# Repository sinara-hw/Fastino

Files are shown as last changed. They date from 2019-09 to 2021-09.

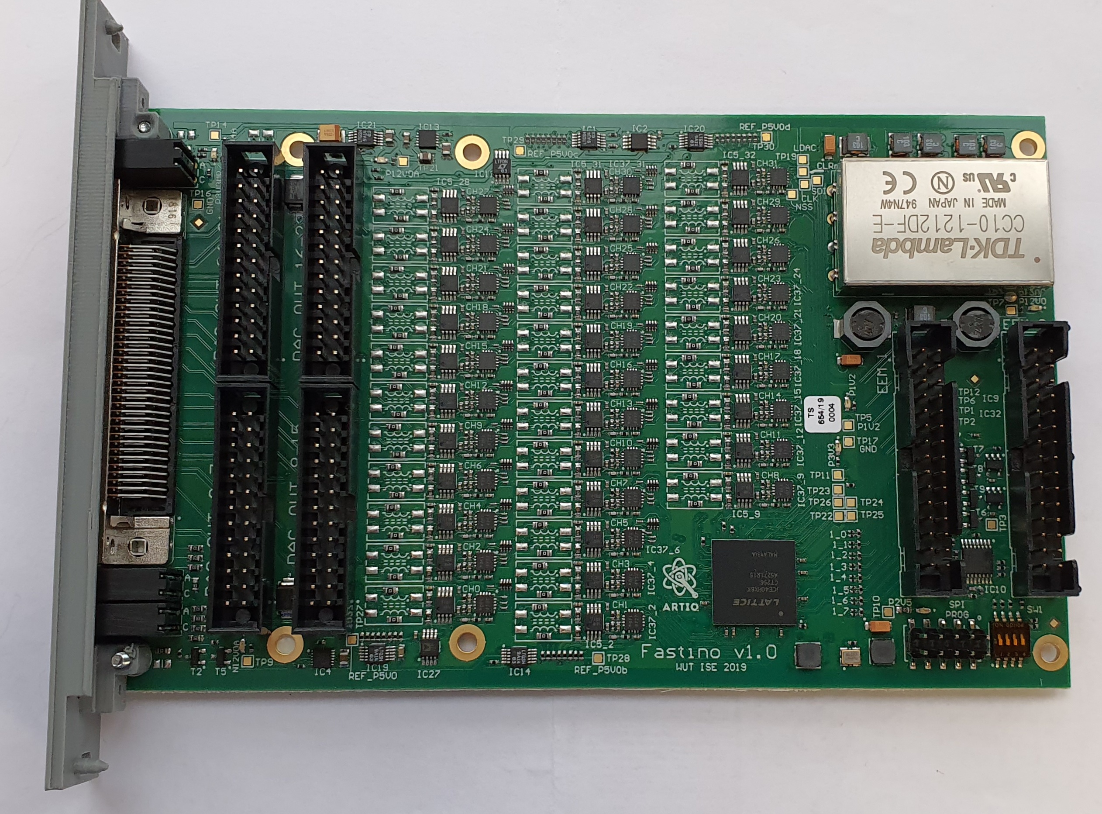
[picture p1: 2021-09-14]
2019-12-04 11.57.32.jpg

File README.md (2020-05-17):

# Fastino
Fast 32-channel, 3MS/s per channel, 16bit DAC EEM card compatible with Zotino

## Design Files

Design files (schematics, PCB layouts, BOMs) can be found at [Fastino/Releases](https://github.com/sinara-hw/Fastino/releases).

## Wiki

More information can be found on the [wiki](https://github.com/sinara-hw/Fastino/wiki).

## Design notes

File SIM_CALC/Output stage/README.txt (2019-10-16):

LTspice output stage simulations
================================

This directory contains the LTspice source files used in the 
design phase of the Fastino output stage.

 - Design.asc: The proposed output stage design.
 - Design Monte-Carlo tolerance analysis.asc: A component
   tolerance analysis for the proposed design (mc() in LTspice
   uniformly samples from the given relative tolerance region).
 - Design with MFB second stage.asc: An alternative design
   providing enhanced high-frequency roll-off at the cost of an
   extra matched resistor pair and slightly increased noise and
   power dissipation.
 - Noise estimate using DAC matched Rs.asc: A quick estimate of
   the output noise from the DAC-internal matched resistor pair.
 - Stabilizer output stage design.asc: For comparison, the
   output stage of the Stabilizer v1.0 two-channel
   microcontroller servo.

The macromodels for the OPA197 and AD8620 can be downloaded from
the respective manufacturer's websites; place them somewhere on
the library search path (in the easiest case, this directory):

 - http://www.ti.com/product/OPA197/toolssoftware
   (the PSpice model can be used with LTSpice)
 - https://www.analog.com/media/en/simulation-models/spice-models/ad8620.cir

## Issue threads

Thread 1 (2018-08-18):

[RFC] new EEM: Fastino (faster version of Zotino)

dtcallcock, 2018-08-18:
A faster DAC than Zotino.

Roughly order of magnitude performance improvement by most metrics at the cost ob being only 4 channels.

# Use cases

### Voltage output version of SU servo

[SU servo](https://github.com/m-labs/artiq/tree/master/artiq/gateware/suservo) is an 8ch servo for Artiq based on [Kasli](https://github.com/sinara-hw/Kasli).  It uses the 8ch [Sampler](https://github.com/sinara-hw/Sampler) ADC as the input and changes the phase/amplitude/frequency of a pair of [Urukul](https://github.com/sinara-hw/Urukul) 4ch DDS cards as its output.  It is capable of a ~2us latency.  An obvious extension of SU servo would be to have a voltage output instead.  This would reuse the Sampler, Kasli, and much of the gateware.  The current EEM DAC, [Zotino](https://github.com/sinara-hw/Zotino) is not well suited for this application for various reasons though.

### General fast DAC

There is a bit of a gap between Zotino (update rate of 1MSPS divided between all 32 channels) and the super high spec [Shuttler](https://github.com/sinara-hw/sinara/wiki/Shuttler).  Are there any specific use cases to be found in this gap?

# Implementation

### Channel Count

4 channels and 4 SMAs on a 4HP front panel

### DACs

4x 16-bit single channel DACs
[AD5542a](http://www.analog.com/en/products/ad5542a.html) or similar

3 MSPS (all channels simultaneously)
1 LSB INL (4x)
11.8 nV/√Hz noise spectral density (23x)
1 μs settling time (20x)
0.05 ppm/°C temperature drift (100x)

Numbers in brackets refer to improvement over the [AD5372](http://www.analog.com/media/en/technical-documentation/data-sheets/AD5372_5373.pdf) on Zotino.

### EEM

1x SCLK
4x SDI
1x LDAC
1x CLR
1x spare

I2C readout of termination and polarity settings.

### Output Ranges

Output impedance of 450Ohm

Bipolar
- -1 to 1V into 50 Ohm load
- -10 to +10V into high-Z load

Unipolar
- 0 to 1V into 50 Ohm load
- 0 to 10V into high-Z load

DIP switch to select between bipolar/unipolar.
DIP switch to connect on-board 50 termination.

gkasprow, 2019-01-13:
Anyway, let's wait until we debug the Stabilizer (DAC part) and Banker (FPGA part) first.

hartytp, 2019-07-07:
Thoughts about Fastino having played around with Stabilizer:
- Generally, looks like we can reuse the analog parts from Stabilizer without major changes
- The in-band noise is basically white at ~100nV/rtHz. That agrees with a back of the envelope from the schematic; DAC is 12nV/rtHz (and there aren't really any lower noise options); AFE gain is 5 to get +-10V with 4.096Vref (can potentially use a gain of 4 with 5V ref but there is the usual issue around ensuring that the supply voltage is actually higher than the reference voltage once accuracy of all components is accounted for); the rest is largely due to the Johnson noise of the ~10k resistors we're using in the AFE. For reference, the NIST PDQ is also around 100nV/rtHz and the ETH "DEATH" boards are around 70nV/rtHz. We could get the noise down a bit by e.g. increasing the ref voltage (decrease AFE gain) and decreasing the resistors used in the dividers. Before doing that we should consider what we actually need for experiments and whether it's worth the fuss
- Still need to measure the noise at higher frequencies to check what the active filter is doing. My guess is that it doesn't do much since the final stage noise + gain is still relatively high (again due to the 10k resistors). Probably fine as we can put a passive filter near the trap, but worth having a think about this.
- The reference buffer solution on Stabilizer seems good. We may be able to get away with 1 ref buffer per 8 (or more) DACs (instead of the 4:1 ratio on Stabilizer) particularly if we switch to the LT3045 (lower output impedance), but needs simulation.
- The major piece of work is the digital section (deserializer interface) which needs to be prototyped before we can actually start on the HW

gkasprow, 2019-07-07:
The deserializer can be easily prototyped with Humpback. I plan to reuse its digital section entirely. The sampler can be attached to it and SPI lines can be directly routed to the FPGA after removing the '125 buffers.

hartytp, 2019-07-07:
> The deserializer can be easily prototyped with Humpback. I plan to reuse its digital section entirely.

I'm not so worried about prototyping on HW itself -- you've shown that you can lay out FPGA/CPLD projects like this very reliably. What I'm thinking about is writing the code ahead of time and checking it builds, meets timing, etc. It's not a huge job, but it needs some thought to get right

gkasprow, 2019-07-07:
the question is if we want to have independent control of all DACs? Or we can assume that they will be updated simultaneously and we can route common CLK  and NSS lines. We have ~90 3.3V IO lines. Rest are in the 2.5V bank. We can route only 2 dedicated lines per DAC. If we add 2.5-> 3.3V converter we could route 3 individual lines to every DAC, but I'm not sure if that is necessary.

hartytp, 2019-07-07:
Yes, it needs some thought. I have some ideas, but I'd prefer not to start a conversation about it until I've given it some more thought :)

gkasprow, 2019-07-07:
Another question we need to ask is the application. Is the board going to be used for fast update of a single channel, massive streaming of data to all channels or both? And, is the latency critical?

jordens, 2019-08-29:
@gkasprow could you give me write access? I'd like to add specification and details to the wiki.

jordens, 2019-08-29:
@gkasprow Are you sure about that IO count? On Banker you have routed 128 IOs plus 16 direction signals on three banks that could be 3.3V (not counting the LVDS bank at 2.5V). That would map to 4 signals per DAC plus spares for LEDs and shared CLR.

gkasprow, 2019-08-29:
@jordens I assumed that will have only two EEM connectors. Some of 2.5V can be used for 3.3V signaling as outputs.

gkasprow, 2019-08-29:
I gave you access rights.

jordens, 2019-08-29:
Even with three eem connectors there should be enough io to give each dac 4  lvcmos 3.3 signals. That's sufficient for completely independent control. Clr can be shared.

gkasprow, 2019-08-29:
True. I didn't count one bank. We have enough pins.

gkasprow, 2019-08-30:
Is there any use case for 3 EEMs?

hartytp, 2019-08-30:
> Is there any use case for 3 EEMs?

I don't think so. My assumption is that we can probably run the whole thing from a single EEM (see Robert's spec on the Wiki), but having a second one for contingency/expansion is a good idea. That would still allow us (ignoring current consumption, heat etc) to drive 192 DAC channels per Kasli.

hartytp, 2019-09-06:
Hardware, gateware and software funded by U Oxford

Closed 2019-09-06.

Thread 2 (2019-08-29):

analog design notes

hartytp, 2019-08-29:
**noise density**
- for HOA2, 43Ca+, 1MHz secular frequency: 0.5nV/rtHz on all electrodes (uncorrelated) gives 10qps (quanta per second) heating rate
- heating rate is quadratic in voltage noise density (linear in PSD)
- heating rate scales as inverse of secular frequency
- we'd like to aim for <1nv/rtHz at our trap, assuming a passive multi-pole RC filter between Fastino and the trap
- assume we use a filter like https://ws680.nist.gov/publication/get_pdf.cfm?pub_id=912958 and assume Fastino has an output resistance of around 33 Ohm (to isolate the OpAmp from cable capacitance)
- assume we get around 35dB of filtering, that's a factor of ~50 in linear units. So, the noise density out of Fastino in the stop-band of the Fastino's filters needs to be <~50nV/rtHz, which isn't trivial but should be doable with careful design.

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

- rough ball-park of heating during a splitting operation. Suppose the secular frequency drops down to 300kHz for 30us and we want to limit axial heating to <1 phonon. That's a max heating rate of 33kHz at the lower frequency
- for 1MHz secular, that would be a noise density of `0.5*sqrt(33e3/10)=30nV/rtHz`. For 300kHz it needs to be 10 quanta/second.
- We'll likely be in the 50-100nV/rtHz, so heat by 25-100quanta over that splitting operation.
- noise sources:
  - AD5542A (DAC) Vn =12nV/rtHz after an AFE gain of 5 that's 60nV/rtHz. IIRC there isn't a significantly lower noise DAC around at this kind of BW, so this is a fairly hard limit. Only affects "in-band" noise though as removed by AFE filter stages
  - AD8620ARZ (AFE OpAmp) Vn=6nV/rtHz. IIRC the noise from the second OpAmp is still present after the filter with a gain of 2.5, so that's 15nV/rtHz which is fine.
  - OpAmp In negligible since JFET
  - [ ] to do: SPICE noise model for Stabilizer, look at relative contributions. Measure on current hardware to check reality matches the model

@dnadlinger IIRC you had a nice table of the noise for the various "fast DAC" cards around. Would you mind posting that for reference?

**slew rate**
- I'd like to be able to output FS sinusoids at a few hundred kHz without being slew-rate limited
- peak slew-rate limited is `10V*2*pi*300kHz=12.6V/us` (in practice a little less is needed due to attenuation by the filter)
- the DAC has a slew rate of 17V/us after an AFE gain of 5 that's 85V/us
- the AD8620ARZ used on Stabilizer has a slew rate of min 40V/us
- so this should be completely fine!

**other comments**
- since we're using much more stable DACs than Zotino (and stable dividers) we don't need a TEC
- we'll need to do proper PI and thermal simulations to check how hot this gets

hartytp, 2019-08-29:
From Ludwig's thesis:

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

So the in-band noise would be about the same as the ETH cards.

dnadlinger, 2019-08-29:
Yep, the table I had was the one from Ludwig's thesis you posted.

hartytp, 2019-08-29:
- [ ] to check: can we switch to a 5V ref and 4xAFE gain for slightly lower noise?

hartytp, 2019-08-29:
> to check: can we switch to a 5V ref and 4xAFE gain for slightly lower noise?

AFAICT the DAC is fine with Vref=Vsupply=5.5V. IIRC the choice of 4.096V for Stabilizer was because of the ADCs, not the DACs.

For 5.5Vref we'd get nearly a factor of 2 reduction in heating rate for low axial frequencies which is definitely worth having. Lowering the gain of the final stage also lowers the out-of-band noise floor so all around a good thing to do. But, needs double checking from the data sheet that this is allowed.

dnadlinger, 2019-08-30:
Regarding op-amp noise, the OPA827 is 4 nV/rtHz at 1 kHz, i.e. 33% lower. Slew rate needs a look, though.

hartytp, 2019-08-30:
> Regarding op-amp noise, the OPA827 is 4 nV/rtHz at 1 kHz, i.e. 33% lower than the AD8620, and cheaper as well. Slew rate needs a look, though.

IIRC I rejected that originally because I wanted a dual OpAmp.

Not sure if we have the board real-estate for singles. Since the DAC is 11nV/rtHz the OpAmp noise does alter the overall output noise that much, although lower cost is good...

hartytp, 2019-08-30:
> and cheaper as well.

Not really since you'd need two of them and only one OPA8620

jordens, 2019-08-30:
The other relevant quantity here is the the output range. The +-10V is sounds about right for larger traps (i.e. HOA2 with 140µm characteristic distance). But smaller traps can live happily with less range. And even going to -4 to +8V would help with the noise. IME transport waveforms tend to be pretty asymmetric and need more positive headroom. At least in the traps that I built and worked with. Dunno for HOA2.

dnadlinger, 2019-08-30:
Ah, right, I only had a look at singles. I actually meant the new OPA828, though, but that is still only single, and not available in packages smaller than SOIC.  £3.51 in qty 1000 on Digi-Key, though, vs. £9.95 for the AD8620ARZ.

jordens, 2019-08-30:
And do check the quiescent current. The fancier opamps sometimes buy low noise with lots of quiescent bias current for internal stages.

gkasprow, 2019-08-30:
If we get rid of CMCs, we would spare some real estate for the second opamp.

hartytp, 2019-08-30:
> If we get rid of CMCs, we would spare some real estate for the second opamp.

Sure. All things equal, I'd still prefer to use dual OpAmps though and keep the layout compact.

> And do check the quiescent current. The fancier opamps sometimes buy low noise with lots of quiescent bias current for internal stages.

Yes, thermal/power issues are high on my list of concerns for this design.

dtcallcock, 2019-08-31:
> The +-10V is sounds about right for larger traps (i.e. HOA2 with 140µm characteristic distance).

HOA 2 is rated to +/-20V according to the [manual](https://prod.sandia.gov/techlib/access-control.cgi/2016/160796r.pdf).  Might be worth checking if users of overly-bulky ions like Yb+ actually make use of this capability? @jbqubit ?

> And even going to -4 to +8V would help with the noise. IME transport waveforms tend to be pretty asymmetric and need more positive headroom.

OPA8620 is a 26V opamp so if we went this route perhaps we could make it so that one could switch between -4/+8 and -8/+16 (probably via population options)?

hartytp, 2019-08-31:
@jordens
> The other relevant quantity here is the the output range. The +-10V is sounds about right for larger traps (i.e. HOA2 with 140µm characteristic distance). But smaller traps can live happily with less range. And even going to -4 to +8V would help with the noise. IME transport waveforms tend to be pretty asymmetric and need more positive headroom. At least in the traps that I built and worked with. Dunno for HOA2.

@dtcallcock
> HOA 2 is rated to +/-20V according to the manual. Might be worth checking if users of overly-bulky ions like Yb+ actually make use of this capability? @jbqubit ?
> OPA8620 is a 26V opamp so if we went this route perhaps we could make it so that one could switch between -4/+8 and -8/+16 (probably via population options)?

These are all valid points. Taking a step back for a moment, I think it's important to have a clear mission statement for any project to avoid a bloated, overly-complicated design.
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
hartytp, 2019-09-02:
I'm not too worried about the larger offsets, since the [divider resistors](http://www.farnell.com/datasheets/1932989.pdf?_ga=2.39542499.197723750.1567441610-1538663289.1567441610) are only good to 5e-4 ratio = 10mV on 20V.

So, I'd say the next step is to simulate the filter transfer function for a few different OpAmps from that selection and pick the lowest current consumption amp that does the job. Agreed?

dnadlinger, 2019-09-02:
> Agreed?

Yep; basically, if the OPA2197 is quick enough, there is little reason to look somewhere else. ADA4625 or OPA828 for faster JFET amps with significantly lower 1/f noise.

hartytp, 2019-09-02:
> ADA4625 and OPA828

I discarded those because they're quite pricey and thirsty so I don't really see the appeal over the significantly cheaper OPA2156.

> with significantly lower 1/f noise.

Is that a concern? LTC6655 is 0.25ppm 1/f noise, so 5uV on 20V output. All the amps you selected have low 1/f noise compared with that, so it's not worth worrying about, right?

dnadlinger, 2019-09-02:
> low 1/f noise […] not worth worrying about, right?

1.9 µV over 5.5 V is 0.4 ppm, plus if we really wanted, we could filter down the LTC6655 further using a quiet chopamp and capacitor-leakage-reduced RC filter setup. I don't think this is necessarily worth worrying about, though.

hartytp, 2019-09-02:
> 1.9 µV over 5.5 V is 0.4 ppm

Thank you, yes you're right, it is more important for the first OpAmp. Still, even then we're close to reference limited. I'd argue that I'd prefer reduced cost/current consumption to a factor of 2 in 1/f noise for this design.

Or, a different argument: it's actually quite hard to hit the reference's 0.25ppm noise floor, particularly in an environment with high thermal loads. I suspect that unless we keep the power dissipation down and maybe pot it, we'll measure a few times that. In which case, the OpAmps will contribute but probably not dominate.

dnadlinger, 2019-09-02:
> it's actually quite hard to hit the reference's 0.25ppm noise floor

Agreed; Fastino just flapping around in the (rack fan) will almost certainly be worse than 0.4 ppm; even more so the full system. I just wanted to point out that the design isn't optimised for low-frequency noise, in case someone thinks they'll be limited by it in their use case. May they speak now, or…

hartytp, 2019-09-03:
Tina TI simulation of the filter on stabilizer

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

With the OPAx156 TF is
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

OPA197:
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

hartytp, 2019-09-03:
So, I'd actually argue that the filter performance isn't enough justification to go for the faster OpAmps.

Anyone against going for an OPA2197 for the active filter (and also on stabilizer)?

hartytp, 2019-09-03:
I'm **much** more worried about power dissipation than a few dB on the active filter.

hartytp, 2019-09-03:
Slew rate is 20V/us, which is fine

dnadlinger, 2019-09-03:
We can also go to a multiple-feedback topology for better high-frequency attenuation, although I suppose we'd be more sensitive to part-to-part variations.

hartytp, 2019-09-03:
> We can also go to a multiple-feedback topology for better high-frequency attenuation, although I suppose we'd be more sensitive to part-to-part variations.

True. Feel free to suggest something ;)

jbqubit, 2019-09-03:
> Yeah, and looking at the strike-throughs on the Sinara team page,
> I'm not sure there are even any Yb-ers left.

There's quite a few Yb+ Sinara users. Currently using Sinara there are 5 traps at UMD and 3 traps at DOD  labs. Soon there will be 3 more Yb+ traps at UMD using Sinara. I'll pester people locally who are following the Sinara hardware discussions to add themselves to the sinara [wiki](https://github.com/sinara-hw/meta/wiki/Team#umd).

>HOA 2 is rated to +/-20V according to the manual.
>Might be worth checking if users of overly-bulky ions
>like Yb+ actually make use of this capability? @jbqubit ?

Assuming 171Yb+, HOA-2.0, +/-1 V and potential optimization to maximum axial frequency the result is 700 kHz. +/-10 V would give 2.2 MHz, pretty much the bare minimum. I'd say +/- 20 V is desirable but not at the cost of missing other design objectives.

> On the subject of asymmetric voltage ranges:

Agreed that this is an unwanted level of optimization. Let's keep this somewhat general purpose.

hartytp, 2019-09-03:
Let’s aim to do our best to support higher voltage ranges as a population option (above +-16V or so will need a different opamp). This will need different voltage set resistors for the regulators, different gain set and filter rcs is etc so it’s not something we’ll do now but interested parties can do it when the need arises

Closed 2019-09-07.

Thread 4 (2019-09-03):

filter design

hartytp, 2019-09-03:
Noise plot for the stabilizer filter with OPAx197:
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

- [ ] reduce gain to 2x since we'll use a 5Vref and re-simulate
- [ ] look into reducing the peaking

This looks rather noisy all-told. Worth at least considering reducing resistor values.

@gkasprow how did you calculate the filer components?

hartytp, 2019-09-03:
Scale all impedances down an OOM to reduce the noise and look again at the FT

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

The noise does decrease, but so does the filter response, suggesting that the non-idealities for the OpAmp are a real limitation here. Probably less of an issue with a lower gain, but strongly suggests we need to do some work on filter design

gkasprow, 2019-09-03:
That's why I added 7.5pF cap to compensate for opamp Cin. You should not change it.

hartytp, 2019-09-03:
> That's why I added 7.5pF cap to compensate for opamp Cin. You should not change it.

Okay, but for this filter/OpAmp 7p5 isn't enough. Anyway, requires some tuning. Where did you get the other component values from though?

gkasprow, 2019-09-03:
I selected value to create a compensated divider. It may need tweaking.

gkasprow, 2019-09-03:
The other values were proposed by ADI filter wizard.

hartytp, 2019-09-03:
> The other values were proposed by ADI filter wizard.

Thanks!

hartytp, 2019-09-03:
@gkasprow what filter did you design? Butterworth? What cut-off and Q?

Note to self one of many references on filter design http://www.ti.com/lit/an/sloa049b/sloa049b.pdf (p7 for MFB)

gkasprow, 2019-09-03:
I don't remember. It should be in the design files I gave you access to.

hartytp, 2019-09-03:
@dnadlinger MFB is indeed significantly better in terms of attenuation. Needs a bit of tuning to trade off noise peaking v attenuation and also a Monte-Carlo sim to look at gain tolerance.

dnadlinger, 2019-09-03:
@gkasprow: Do you have any experience with MFB (vs. Sallen-Key) low-pass filters in precision circuits? I'm basically waiting someone to tell me that MFB is a silly idea for a reason I didn't consider.

hartytp, 2019-09-03:
@dnadlinger the biggest reason I'm aware of is that the AC gain becomes sensitive to component values in a way it's not for SK.

hartytp, 2019-09-03:
First thing to fix is the resistor network values. 1k would be great for noise, but then you're looking at the OpAmp sourcing/sinking up to 10mA. Which seems to much if we want any appreciable channel density. So, I guess we need to set the minimum resitance that we source/sink the full 10V through to be something like 10k, which is a bit painful from a noise perspective, but not much choice.

gkasprow, 2019-09-03:
I never tried MFB

hartytp, 2019-09-03:
I think if you do the spice sim and monte-carol to check the tolerances then you'll get all the info you need. Maybe also just check the step response for good measure.

dnadlinger, 2019-09-03:
Re MFB, I'm more worried about non-obvious gotchas (op-amp GBW changes, etc.), which I can't easily Monte-Carlo-simulate in LTSpice. From what I've seen, many people seem to prefer Sallen-Key, but I'm unsure as to why.

Slight changes in step response with component tolerances wouldn't be too big of an issue – if you really care (for accurate transport/pre-emphasis), you'd measure the transfer function of all your filters up to the trap per-channel anyway. Weird drifts, on the other hand, would screw us (although I don't have a good sensitivity estimate for that).

I guess the issue with power dissipation re channel density would mostly be potential drifts induced by the DAC code-dependent heat load? 100 mW * 32 = 3.2 W doesn't seem to be an insurmountable problem.

hartytp, 2019-09-03:
> I guess the issue with power dissipation re channel density would mostly be potential drifts induced by the DAC code-dependent heat load? 100 mW * 32 = 3.2 W doesn't seem to be an insurmountable problem.

Not insurmountable, but still quite a lot of power! (And actually worse than your calculation since one OpAmp sources while the other sinks, 12V rails not 10V etc). Add to the quiescent current and the the board is drawing quite a lot of current.

As you say, my worries are mainly thermal heat load, and particular dynamic thermal heat load making things unstable.

10k shouldn't be too bad since the in-band noise is still dominated by the DAC, while the high-frequency stuff (a) can be removed by a later passive filter (b) for the MFB topology, I think it's capacitively shunted away in any case, so not a problem.

hartytp, 2019-09-03:
@dnadlinger http://www.ti.com/lit/an/sbfa001c/sbfa001c.pdf p10-11

dnadlinger, 2019-09-03:
@hartytp: Thanks – yep, those were the points I was aware of (without gain, the op-amp in Sallen–Key is just a follower, so no stable DC gain setting resistor pair needed), but people just seems to use it by default even in situations where the lack of high-frequency attenuation hurts… I'll (LT)Spice up a design in a bit once I got that two-qubit Gate Set Tomography working.

gkasprow, 2019-09-06:
I want to finish the Stabilizer. What is the conclusion about the filter?

hartytp, 2019-09-06:
This shouldn’t be a release blocker for stabilizer. We can always change in a future release

dnadlinger, 2019-09-07:
Observation: The DAC-internal matched resistors for bipolar shifting are 28kΩ each. Thus, each resistor contributes a bit more to the total noise than the 6.2 kΩ DAC resistors (noise gain 1 instead of 2, but four times the resistance). On Stabilizer, those resistors raise the total noise from ~90 nV / rtHz to ~120 nV / rtHz in the filter pass band.

Thus, what about using an external, say, 4.99kΩ matched resistor quad instead of the DAC-internal one, which would allows us to put all the gain in the first stage? Here is a sketch (LTspice file attached):
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

(R4 is two resistors of the quad paralleled.)

With the maximum reference voltage of 5.5 V, we'd get ±11 V output, and roughly the following performance:

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

The second stage is a Sallen–Key filter to avoid having to use a second matched resistor network for gain accuracy (drift), but as it is in unity gain, the high-frequency behaviour is a bit better.

All in all, the above simulates as 50 nV / rtHz at 10 kHz, or a bit less than half the Stabilizer output stage.

(Component values are not optimized yet; I started from a third-order Butterworth response made from a single-pole and a Q = 1 two-pole stage, and reduced C3 from 404pF to 360 pF to reduce the peaking a bit. I can run a sensitivity MC analysis if this look sensible.)

[Fastino output stage LTSpice.zip](https://github.com/sinara-hw/Fastino/files/3586951/Fastino.output.stage.LTSpice.zip)

dnadlinger, 2019-09-07:
@hartytp: What do you think about going for ±11 V as we can support that without degrading noise performance? (Vref on the AD5542A is specified up to 5.5V.)

hartytp, 2019-09-07:
I did think about that, but doesn't seem worth it IMHO. e.g. where will that ref come from?

dnadlinger, 2019-09-07:
We could use a single 10k/1k matched quad to produce 5.5V from a 5V LTC6655.

hartytp, 2019-09-07:
Yes, I'm not really against it. Just not sure I can be bothered to go for a less common range for such a small win in S/N. If you want to go for this I don't object...
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
gkasprow, 2019-09-10:
This the reason I added 10k at the DAC output to lower overall tolerance. Of course, this adds noise. We could make the first stage at a slightly higher frequency than the rest of the filter poles to make sure it won't dominate the filter response.

hartytp, 2019-09-10:
> We could make the first stage at a slightly higher frequency than the rest of the filter poles to make sure it won't dominate the filter response.

Exactly, I suspect we'll do something like that. But, that's an easy change to make later on since it's just an RC BOM change.

jordens, 2019-09-14:
The filter corner looks ok. But it has that bump between 2 and 10 MHz where it attenuates only between 60 and 70dB (eyeballing the plots). This is not what one would typically want from a 16 bit reconstruction filter for 2MS/s and it deviates a lot from the expected rolloff for a filter of that order.
There are always the trap rf rc filters which will provide more attenuation and I know that the stopband and rolloff are typically a problem for active filters. But still, this is the critical window.
If we decide to generally rely on the downstream trap filters to provide proper stopband attenuation at >1 MHz then maybe this filter should be tuned to serve another purpose, e.g. notching clock leakage.

dnadlinger, 2019-09-15:
> This is not what one would typically want from a 16 bit reconstruction filter for 2MS/s […]

The filter actually dips below the ideal response at ~3 MS/s, so for more attenuation at 2 MHz, we'd need to go to a higher-order design. A bit can of course be gained by accepting some passband ripple.

In any case, using an MFB filter instead for smoother roll-off is an option, at the cost of an extra matched resistor pair and somewhat increased noise/current consumption, see https://github.com/sinara-hw/Fastino/tree/master/SIM_CALC/Output%20stage.

> maybe this filter should be tuned to serve another purpose

I did bring up the possibility for more complex designs a while ago (e.g. notch at target clock frequency) but in the end, it seemed like our best bet for the first revision of Fastino would just be a boring design with conservative, generic choices.

Unless you are planning to mount Fastino directly at the trap can, you'll always want significant passive filtering close to the electrodes anyway, as reaching sub-nV/rtHz on something dangling off a long cable is hard. Assuming some 30–35 dB attenuation at 2 MHz, the total gain at 2 MHz would be around -80 dB, and significantly better at harmonics. This seems good enough to be a workable starting point.

In any case, I don't really want to get involved in choosing the filter response, as I don't currently have the bandwidth for what seems to me to be the most principled approach: Simulate some transport waveforms for my experiment, and choose filter topologies and locations based on target speed and heating.

gkasprow, 2019-09-16:
Can we stay with such filter design and continue routing?
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

hartytp, 2019-09-16:
@gkasprow yes

My reasoning here is that this filter is pretty cheap to implement -- we need an OpAmp here anyway for gain and ref subtraction, and going to an SOIC8 dual AOP2197 adds very little to the cost/power consumption -- and it does make a useful contribution to the filtering, easing the requirements on subsequent passive stages. e.g. it does a decent job of killing image frequencies above 1MHz.

hartytp, 2019-09-16:
Thanks again @dnadlinger for doing this!

gkasprow, 2019-09-16:
@hartytp the most critical routing is already done
Look [here](https://www.dropbox.com/s/uc8q7tafdkh9wbx/Fastino.PDF?dl=0)

hartytp, 2019-09-16:
Nice! I'm still a little worried about digital-analog cross-talk. Particularly for the channels near the FPGA. We'll have to put some thought into grounding and routing to minimize that.

Otherwise, looks really nice!! Really glad to see it so close. Should be fairly quick to finalize once we pick the FPGA.

jordens, 2019-09-16:
@gkasprow don't put too much time into the final FPGA routing yet. I'll have a bunch of change requests.

gkasprow, 2019-09-16:
The FPGA routing is the quickest part of the job thanks to automation - pin swapping tool.
The reference tracks have ground plane below and analog supply plane (not poured yet) above so don't worry about the crosstalks and they are well separated from digital lines.

hartytp, 2019-09-16:
Cool!

jordens, 2019-09-21:
Another note: the filter needs to be really good to kill the ~50mV pk-pk 50MHz digital feedthrough. The -120 dBFS attenuation simulated look good if the opamp models are accurate at those high frequencies and if there is no unexpected coupling (the layout is very tight).

Closed 2019-10-20.

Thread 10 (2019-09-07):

reference distribution

hartytp, 2019-09-07:
- let's make sure we use star trace layouts and wide traces for reference distribution to minimize common impedance cross-talk
- how many DACs to we want to share a reference buffer? 4? 8? @gkasprow once the filter design is complete, can you simulate the cross talk (DAC and AC) due to the DACs + filters so we can see how bad this is

gkasprow, 2019-09-07:
@hartytp that's why I used 0R resistors to force such routing.
I did some simulation in the past and AFAIR two buffers would do the job.
I will play with it once again.

hartytp, 2019-09-07:
> @hartytp that's why I used 0R resistors to force such routing.

Aah, nice trick

> I did some simulation in the past and AFAIR two buffers would do the job.
> I will play with it once again.

When you're done can you upload the spice sim to git please?

NB now we must also take into account the reference subtraction in David's filters...

gkasprow, 2019-09-15:
I did a simulation with 8 loads running at 8 different frequencies from 10k to 1MHz.
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
The result over 20ms:
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
Rippless are below 20uVpp
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

gkasprow, 2019-09-16:
After replacing 10uF caps at the DAC reference inputs, with ceramic ones (10mOhms of ESR), the ripples are twice lower:
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
the worst-case event:
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

hartytp, 2019-09-16:
@gkasprow unlike Stabilizer, Fastino is mainly used open-loop. So, it's not just the AC effects we need to worry about (although, they are important) it's the DC ones too. The capacitors won't affect that.

What's the DC shift in output voltage on one channel as a function of the reference current drawn by the other channels?

gkasprow, 2019-09-16:
I do a DC sweep but I'm not able to measure any voltage drop on . Take into account that we have external opamp that trims the DC response.
The blue line is the LDO output, the green one is the DAC ref input.
sweep 0-200uA
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

With increased current by 1000x
sweep 0-200mA
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
The circuit
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

hartytp, 2019-09-16:
Okay, great! So the green line is just the trace voltage drop? So, that would correspond to degraded INL (and maybe DNL as well if the current/DAC code curve is not smooth), but not to cross-talk?

gkasprow, 2019-09-16:
trace + 0R resistor.

gkasprow, 2019-09-16:
It's roughly 5uV within entire 0-200uA DAC current

hartytp, 2019-09-16:
nice!

How do you think the AC ripple compares with the DAC glitches after going through the filter? The glitches are huge, but the filter will smooth them out quite a bit.

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

gkasprow, 2019-09-16:
The reference glitches are nearly 3 orders of magnitude lower - 10uVpp vs 9mV

hartytp, 2019-09-16:
Right, but after they go through the filters, isn't it the glitch area that really matters?

gkasprow, 2019-09-16:
Yes, it is. It's hard to estimate the area above and below Vout, but they seem to be similar. So it should not affect the DC. Such DAC should be refreshed only when one updates its value to avoid such glitches.

hartytp, 2019-09-16:
@gkasprow one other question: if you replace the LT3042 with a 3045, does that make the glitches smaller? i.e. can we replace 2xLT3042 with 1x3045?

hartytp, 2019-09-16:
Other than that, this seems good. Let's go for 1 ref buffer per 8 channels.

gkasprow, 2019-09-16:
They have exactly the same data for load regulation, line regulation, dropout, etc. They differ mostly with max current and output noise.

hartytp, 2019-09-16:
hmm...I thought the 3045 had a lower output impedance, which would give lower glitches (more output pins IIRC)? But, maybe not...

gkasprow, 2019-09-16:
It has simply bigger transistor. And it is in current source configuration. So, for AC its output impedance is similar. For DC, it is kept low by feedback loop. Your statement would be true if the LDO had an emitter follower at its output.

hartytp, 2019-09-16:
Okay, thanks! Can you make sure to include the spice files for this in the repository somewhere. Then I think we can close. Obviously, just watch out for the trace routing from the ref buffer to the DACs (wide traces, star configuration, traces as short as possible etc etc).

gkasprow, 2019-09-16:
sure. This is how I route the references. I will make these traces even beefer
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

hartytp, 2019-09-20:
@gkasprow NB the reference current drawn by the subtractor stage varies between 0 (5V DAC output) and 5V/10k = 500uA (0V DAC output).

The max DAC current variations are relatively small 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 comparatively

So, we should be simulating for approx 0->500uA instead of the 0->200uA above.

Also, can you plot the step response (as well as the noise trace) for all channels switching from 0->500uA simultaneously. I know there is no DC error due to the OpAmp, but I'm worried about intermediate timescales where the reference impedance rises, but the capacitors are still not low impedance yet.

gkasprow, 2019-10-20:
True, it looks like this is slightly over-engineered.
I also made sure that the traces are thick enough.
But such an approach should give us extremely low crosstalk.

hartytp, 2019-10-20:
@gkasprow So I know what to expect out of the final design, please could you post the following using your model:
(a) step response with all channels going from min to max ref current. I'd like to see this over a wide range of timescales, since the dynamics will be a bit complex; the impedance is low at high frequencies due to the capacitors, but rises with decreasing frequency as the capacitor impedance increases, then drops to very low values towards DC due to the OpAmp feedback. I'd like to check that the step response doesn't do anything nasty at intermediate timescales
(b) the same as before where you pulse all channels on/off at regular intervals

NB the reference current you previously used in your simulation was not correct, since it did not include the current drawn by the reference subtraction (which is now larger than the current drawn by the DAC itself). Please can you correct this before posting?

Thanks! I do not expect an issue with the current design, but worth checking the simulation one last time before finalising

gkasprow, 2019-10-27:
Here is the simulation with all 8 sources switching between 0 and 500uA with different frequencies.
One trace is LTC output, another is DAC input
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

0-500uA sweep
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

All DACs switching between 0 and 500uA with 1KHz frequency. One plot is LTC output, another is DAC input
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

jordens, 2019-10-27:
20uV max. Excellent.

hartytp, 2019-10-27:
@gkasprow wow, that's better than I'd hoped! We probably should have cut the number of reference buffers to save some pennies ;)

Thanks so much for doing the detailed simulations, that will make me sleep much better :) 20uV pk-pk on 20V is 1ppm, which is <0.1LSB pk-pk, so pretty impressive!

One final question: if you let the final simulation run longer (say a few ms), is the change monotonic? Or, is there some time scale where the capacitors start do discharge but the DC feedback is not quite working yet?

gkasprow, 2019-10-27:
I simulated it over 1s or so and started plotting in steady-state. I also limited the LTC filtering capacitance to make it converge faster. I will do such a simulation for curiosity.

gkasprow, 2019-10-27:
edit. The simulation was 30ms and plotting started after 10ms. Once I made it running for 1s.

gkasprow, 2019-10-27:
It took a lot of time...
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

hartytp, 2019-10-27:
Nice! Nothing funny going on at any timescale. Good!

Closed 2019-10-27.

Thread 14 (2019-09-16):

SMPS/LDO power budget

hartytp, 2019-09-16:
To do: check the power budget carefully and ensure we have enough margin. The +-21V converter we currently use is only 6W and it would be easy to exceed that will all channels driving a capacitive load due to un-terminated cabling.

gkasprow, 2019-09-16:
Yes, I plan to replace it with 10W version which is slightly bigger. Do we need much more power than that?

hartytp, 2019-09-16:
I don't think so, but let's double check the power budget.

FWIW, if we went for higher bias current OpAmps, this could be a real problem. But, IMHO EEMs really shouldn't be dissipating much more than 10W or the thermal management will become a killer!

We should consider adding a thermal switch somewhere however.

gkasprow, 2019-09-16:
the thermal switch (IC7) is already on the schematics:)

hartytp, 2019-09-16:
:+1:

gkasprow, 2019-09-16:
With the existing design, we can safely draw +/- 6mA from all channel at once. I assume that we operate with AC signal that consumes 6mA from both +12V and -12V rails. The entire board power consumption is 13W in such case. Without the load, it consumes 7W.

gkasprow, 2019-09-16:
Edit: 12.7W with load,7.5W without the load.

hartytp, 2019-09-16:
R=V/I=10V/6mA=1.7k

So the min DC load is approx 2k. That's fine for us (we will drive basically only the cable capacitance) but worth noting the current limit on the schematic.

I guess if the user shorts too many channels the PSU will current limit and undefined behavior will ensue.

gkasprow, 2019-09-16:
The LDO is 250mA, so it should trip first. It has PG output so we could try to make use of it...
In case we need more power, [15W PSU](https://www.cincon.com/productdownload/EC3SB-V18.pdf) is available with similar dimensions. Its output can be trimmed to +/-13V. It costs similar to CC10-1212DF-E

gkasprow, 2019-09-16:
edit, LDOs are 200mA

hartytp, 2019-09-16:
Cool. Well, let's do the power budget and then make sure we have some margin.

I think that if users want high speed amps for filters etc, or wider voltage ranges, they should make a small daughter card to do that. Otherwise the power consumption on Fastino is just too high

gkasprow, 2019-09-16:
The detailed power budget is [here](https://www.dropbox.com/s/5416p1zyza7l3iu/Fastino_Power_Budget.xlsx?dl=0)

hartytp, 2019-09-16:
thanks.

Well, pick whichever LDOs you think are most suitable and then I'll double check when I do a design review.

jordens, 2019-09-24:
* The LTC6655 only has 0.2V dropout when operated at the 60µA we are looking at. It could be powered from P5V5A or even P12V0A and the P7V0A rail could be dropped.

* Do you really need to burn `4*18mA*5V~400mW` idle power from the reference buffers?

gkasprow, 2019-10-20:
true, 400mW is a lot. I increased these resistors to 1k.
I also removed 7V rail. Good catch.

gkasprow, 2019-10-20:
I also used higher power 10W DC/DC and increased LDO currents to 400mA to give some extra margin to the AFE.
I used LT3045 and LT3094. @hartytp please check IC4 and IC3.

hartytp, 2019-10-20:
Cool, thanks for fixing! Reopening this to remind myself to review the changes. Will close again after review

hartytp, 2019-10-24:
NB agreed that the 10W SMPS is probably overkill, but the lower power one could be a bit marginal with heavy output switching so seems worth keeping the bigger one to give us more margin...

Closed 2019-10-24.

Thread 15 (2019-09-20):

Link design

jordens, 2019-09-20:
I have a prototype for the high speed data link over EEM at
https://github.com/quartiq/fastino
combined with the Kasli prototype at https://github.com/m-labs/artiq/tree/fastino

This works well (<2e-13 BER so far) without an ultimate level of tuning on a typically EEM ribbon cable length of 0.5m and the boards strewn out across the table.
With 3.5m ribbon there is about 1e-9 BER. Still, there are a couple of knobs to tweak that should improve this even for long ribbon cables.

The projected DAC sample rate is 2.55 MS/s each channel. I would leave the filter where it is as this improves the signal quality and puts clock leackage close to the "notch".

Also with this design (due to the SPI-data-word clock relation) there is currently a sawtooth f_sample/3, 14 ns pk-pk deterministic jitter on the DAC update timing. This is irrelevant for most applications but it would become visible as an aliased spur on periodic signals.
If this becomes problematic, there are ways around it.

This supports the case for the ice40. Several change requests to the pinout to follow.

gkasprow, 2019-09-20:
IDC ribbon cable has 120Ohm impedance of single wire in G-S-G configuration. We use it in G-S-S-G config which gives value closer to 100Ohm. DIfferent ribbon cables have different impedances. There are ones with 105Ohm which should be avoided.

hartytp, 2019-09-20:
Very nice. Do we get a red LED or something on checksum errors?

jordens, 2019-09-20:
Interesting. My go-to ribbon cable has 102 ohm in gsg config. http://multimedia.3m.com/mws/media/22052O/3mtm-round-conductor-flat-cable-050in-3365-series-ts0080.pdf

gkasprow, 2019-09-20:
And this cable gives 170Ohm in a balanced configuration. I was wrong in the post above.
We need SGS impedance as low as possible, probably 85Ohm which would be closer to 100Ohm of differential impedance.
People are using  25cm .05 ribbon for PCIe so we should not observe issues at 250MHz.

jordens, 2019-09-20:
Interesting. My go-to ribbon cable has 102 ohm in gsg config. http://multimedia.3m.com/mws/media/22052O/3mtm-round-conductor-flat-cable-050in-3365-series-ts0080.pdf

gkasprow, 2019-09-20:
for high speed one can use this [kind of cable](http://multimedia.3m.com/mws/media/22097O/3mtm-shielded-jktd-flat-cable-050-3517-series-ts0069.pdf)

jordens, 2019-09-20:
You can get a led. Counters for bitslip and crc errors that can be cleared are already there.

hartytp, 2019-09-20:
:)

Closed 2019-09-24.

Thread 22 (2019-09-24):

SPI routing/termination/leakage

jordens, 2019-09-24:
* Please route the SPI CLK lines away from the data/cs/ldac lines if possible.
* We are planning to spend a significant time updating all 32 DACs at full rate (50 MHz SPI, 32 channels, 2.55 MS/s each channel). Do you think this will be problematic in terms of digital feedthrough, ground bounce, simultaneous switching, filter crosstalk? Do we need series termination on SCLK/SDI if that would help with feedthrough?

gkasprow, 2019-09-27:
For such speed, it's worth adding at least series termination on the DAC clock lines. The only unknown is resistance if ICE40 in CMOS mode.
Another worry is ground bouncing. This chip has just a few power pins. The datasheet just says obvious things about SSO, without strict recommendations.

jordens, 2019-09-28:
I am running the prototype on banker currently with lots of SSO activity. How would I measure
and quantify whether there is too much ground bounce? Just power supplies across a cap? Or would I see it on a supposedly steady output (high or low)?

gkasprow, 2019-09-28:
Use two outputs, one H, one L and connect the probe between GND and the outputs

jordens, 2019-09-28:
I'll check.

Re series termination, there are IBIS models for the lattice FPGAs IIRC that should give you some idea of the output impedance.

jordens, 2019-09-28:
The output impedance of a CMOS driver on ice40 is 20 Ohm. That's what they use in the pseudo-LVDS source matching network.

jordens, 2019-09-30:
On Banker, there is about 50-100 mV pk-pk of oscillation on a low output and 200-300 mV pk-pk on a high output in the same bank as 32 toggling 50 MHz SSO.

gkasprow, 2019-09-30:
This is the value I'd expect with such a low number of power supply pins. We can slightly improve it by setting unused pins as outputs and connecting them with supplies so they behave as extra power pins. We don't have many of them though.

jordens, 2019-09-30:
One other option would be to delay half of the SPI buses in a bank by half a SPI clock cycle. That would partially cancel some bouncing.

gkasprow, 2019-09-30:
Yes, this would help. Anyway, the margin is still high, especially for 3.3V supply. We are more sensitive for a low logic level because it must be <0.8V. For H we have a lot of margins so 300mV is fine.

gkasprow, 2019-10-07:
I've selected the longest line connecting DAC28 and FPGA and did some SI analysis.
the Eye diagram with PRBS at 50MHz looks not so bad:
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

gkasprow, 2019-10-07:
with 100R + 100p at  the eye diagram looks much better
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

gkasprow, 2019-10-07:
150Ohm + 47p gives nicer results
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

gkasprow, 2019-10-07:
I added two signals: 50MHz clock at the CLK line, 50MHz PRBS to the DIN and 3MHz 10% duty cycle signals to the LDAC and NSS.
And the crosstalk exceeds 500mV. I'm not surprised by that fact. I planned to place clock lines on the other layer to minimise the coupling.

gkasprow, 2019-10-07:
After I terminated all inputs with 90R + 100p the signals looks not that bad:
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

gkasprow, 2019-10-07:
The simulations include DAC and FPGA IBIS models

hartytp, 2019-10-08:
Good wprk!

jordens, 2019-10-08:
Very nice

jordens, 2019-10-08:
LDAC and NSS ase also edge sensitive. Let's assume for now we ignore LDAC and keep that asserted.
The crosstalk from DIN to NSS may also be an issue. I don't know how bad it is but we can't have unexpected edges on NSS.

gkasprow, 2019-10-08:
Anyway, I will move critical lines to the other layer and add RC termination on every DAC.
There is no reason to save a few $ on 6 layer PCB, the cost will be dominated by the components anyway.

hartytp, 2019-10-08:
> There is no reason to save a few $ on 6 layer PCB, the cost will be dominated by the components anyway.

Agreed. Use as many layers as you need to get a good design.

jordens, 2019-10-09:
Since we are now loading the lines, doesn't this make sso bounce worse?

gkasprow, 2019-10-09:
It will to some extent. I can also add series termination but I'm not sure if it would fit.

gkasprow, 2019-10-16:
no way to fit series termination. We have to live with a RC one.
We can mount it selectively, only for the longest traces or only if SI issues emerge.

jordens, 2019-10-17:
If this proves to dense, we could consider running SCK and maybe even CS_N/LDAC in banks of 4 or 8.

Closed 2019-10-16.

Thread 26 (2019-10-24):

Rethink power sequencing

hartytp, 2019-10-24:
The power sequencing was copied (I assume) from Stabilizer and is way overcomplicated for our need. Not least because all our LDOs now have PG/EN lines!

My comments are:
- [x] I think (please double check this) we can scrap P5V0A and run the DACs of P5V5A. That simplifies things
- [x] Hook up the ref buffer EN/UV pins to the REF_SHDN as well, to ensure that the DAC doesn't get a reference during startup
- [ ] I don't believe any particular sequencing is needed now. I would just tie all PGs together and use them to drive REF_SHDN and the FPGA reset.
- [ ] IC13 and IC4 can be enabled from power on, no enable is needed. (This wasn't the case in Stabilizer since we didn't want the OpAmps driving the ADC during startup, but that's not a problem when we only have DACs).

Can you see any issue with that plan @gkasprow ?

@jordens am I correct in thinking that the ICE40 pins are all inputs/high-z while CRESET_B is asserted, meaning the FPGA can't drive the DAC outputs before the DAC supply is valid?

hartytp, 2019-10-24:
- [ ] hmmm...do we need to keep the FPGA reset asserted until the P1V2 and P2V5 lines are stable?

jordens, 2019-10-24:
Apart from a few special purpose pins (CDONE etc) they are all high-z.

hartytp, 2019-10-24:
@jordens do you see any other potential sequencing issues I've missed? AFAICT, the above points should cover everything and simplify the design

hartytp, 2019-10-24:
LT3045: max EN 22V, threshold is 1.24V
LT3094: max is 22V to gnd or 30V to Vin, threshold is 1.26V
TPS62175: max EN is vin + 0.3 (so 12V), threshold is 0.9V
NCP3170ADR2G: max EN is Vin + 0.3, threshold is 1.4V
AUR9705: max EN is Vin + 0.3, threshold is 1.5V
LTC6655: max EN is Vin + 0.3V, threshold is 2V

LT3045: max PG is 22V
LT3094: max PG is 19V (30V-13V)
TPS62175: PG max is 7V
NCP3170ADR2G: max PG is Vin + 0.3V

So, it looks like we can tie all the PG lines together with a weak pull up to 3V3 to limit current transients (or if we want to be paranoid, stick diodes between PG and Vin lines to stop PG going above Vin, but a 100k pull-up seems easier).

jordens, 2019-10-24:
All good from my side. If the digital part (FPGA) is carried from Banker/Humpback. No special sequencing.

gkasprow, 2019-10-27:
Right, we don't have any ADCs that could be damaged by wrong sequencing.

gkasprow, 2019-10-27:
One sequencing we need is to make sure DACs wakeup first to not cause the latchup from FPGA data lines. But we already have it.
We may also want to make sure that 12V wake up after the DACs outputs are stable to limit huge +/-12V transients at the outputs. So, I'd leave the power sequencing as it is.

hartytp, 2019-10-27:
I think the simpler sequencing (see my comment above)would be much cleaner and easier to understand and debug.

It ensures the fpga is held in reset until the dac supply is stable. It ramps the reference up slowly to avoid output transients

gkasprow, 2019-10-27:
I'm not sure that the reference will ramp smoothly. It would be true without DC stabilization loop

gkasprow, 2019-10-27:
I would even turn on the AFE supply from FPGA after we make sure that DACs have mid-range output state. Anyway, I think we can scrap the LM393 circuit.

hartytp, 2019-10-27:
Well, even so, output transients don’t worry me so much. Many opamps have transients even with their inputs grounded. I am happy assuming the load can handle +- 12V

hartytp, 2019-10-27:
Okay, yes I’d be happy controlling the afe supply from the fpga. Anyway the dac output is high z so won’t damage the opamp input in case of sequencing errors.

gkasprow, 2019-10-27:
OK, let's go for it. the simpler, the better. I remember a discussion about DIO and did my best to ensure there are no transients at the outputs during power-up.

gkasprow, 2019-10-27:
I'm not worrying about the DACs but about the load:)

gkasprow, 2019-10-27:
So, now we have the following sequencing
1. P5V4 wakes up first, powers DACs
2. then FPGA gets power to avoid DAC latchup
3.  Then DAC reference is enabled and FPGA is configured.
4. Once FPGA resets DACs, +/2 12V AFE is enabled.

gkasprow, 2019-10-27:
In the end, the front panel PG LED is on using +/-12V LDOs PG.

Closed 2019-10-27.

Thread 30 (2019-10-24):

LDO input capacitance

hartytp, 2019-10-24:
The LT3045 and LT3094 require a minimum of 10uF input capacitance and recommend low ESR capacitors. Are you sure the 1uF ceramic + 10uF electrolytic will do, or should we replace the 1uF with 10uF ceramic?

Also applies to ref buffers

hartytp, 2019-10-24:
NB I know we've had this discussion before, but the LT3045 set capacitor is recommended to be ceramic. I guess we don't care in this case as we're not relying on this to be massively high stability, but worth noting
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

hartytp, 2019-10-24:
- [ ]  for the reference buffers, the set capacitors should be ceramic as recommended by LTC

gkasprow, 2019-10-27:
what about the noise? Ceramic ones like X7R are good microphones...

gkasprow, 2019-10-27:
I changed the input caps to 22uF

gkasprow, 2019-10-27:
@hartytp what about if we solder ceramic capacitor in one channel and compare results between the channels to see if such solution pickups the noise?

hartytp, 2019-10-27:
> what about the noise? Ceramic ones like X7R are good microphones...

Here's the way I look at it...we have two potential imperfections -- microphonics or leakage current -- and we have to pick one. Which one is worse depends completely on the application.

For the kind of lab environment we use Sinara in (e.g. mounted in a 19'' rack with a fan) I've never observed issues due to microphonics (we have many designs with LT6655/LT304x with large ceramic capacitors which are ultra-low noise). So, I don't find this to be a problem in our case. I can imagine that equipment going into a van or something would be very different.

On the other hand, temperature-dependent leakage can be a real problem where DC stability is required. Do the capacitors you use have a specification for the leakage temp co? I imagine this will dominate the stability of the circuit.

Having said that, in this case the leakage is almost certainly less of an issue because it is stabilised by DC feedback for the critical references. Microphonics can be more of an issue as they have more high-frequency content.

Note that we have a large ceramic on the LT6655 output, so we are using both in this design!

Anyway, looking again, i'm happy with the current situation, so let's leave it as is.

Closed 2019-10-27.

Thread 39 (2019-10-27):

design review

hartytp, 2019-10-27:
- [x] power budget needs updating to reflect the fact that we now have a single 5v4 rail, not 5V0 and 5V5
- [x] why have you annotated the `_LX` nets? what do you connect to them?
- [x] since you're now using the PG output of IC13, I assume you meant to add a PGFB divider there as well?
- [x] Don't the ref buffers need 10uF ceramic input caps to ensure stability? Currently they are electrolytic, which could be too high ESR/ESL
- [x] ref buffer Ilim still does not match the annotation (data sheet says it's 125mA/kOhm, but it's a 220Ohm resistor, which does not match the 27.5mA specified current limit)

Other than that, all looks good to me! Assuming @jordens has no final feedback, let's send.

@jordens NB the new requirement to enable the AFE power supply from the FPGA.

hartytp, 2019-10-27:
@gkasprow one other thing: the 4 special LEDs on the FP have two-letter names, which can be a bit unclear to new users. Could we have something like an annotation of the first page that explains the functions of these LEDs?

gkasprow, 2019-10-27:
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
PG - power good
FD - FPGA done
OT - overtermp
UL - User LED

I placed it also on the schematic

gkasprow, 2019-10-27:
_LX nets are for Hyperlynx to know where the power lines are. I can remove after simulations.

hartytp, 2019-10-27:
If you haven’t finalised the files can we swap ul for err or something. It will be a crc error on the data link

hartytp, 2019-10-27:
Anyway thanks again for another really lovely design! Very much looking forward to testing it on ions

gkasprow, 2019-10-27:
OK, ERR is fine.

Closed 2019-10-27.

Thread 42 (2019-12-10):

Fastino testing

gkasprow, 2019-12-10:
I wrote a simple VHDL code that blinks front panel LED, turns the AFE power on and loads 32-nd DAC with some data. All of these work fine. All voltages have correct values so I think I can send the boards for further testing

gkasprow, 2019-12-10:
That's not that easy. There is a problem with output stage gain. When the DAC gives 2.5V, w get 5V at the output. When it gives 5V, there is 11.9 at the output

gkasprow, 2019-12-10:
the gain is OK, but there is a problem with output stage bias voltage. It is not 2.5V.

hartytp, 2019-12-10:
oops...what did we mess up?

hartytp, 2019-12-11:
Did the test points show 5V for the reference voltage?

hartytp, 2019-12-11:
> That's not that easy. There is a problem with output stage gain. When the DAC gives 2.5V, w get 5V at the output. When it gives 5V, there is 11.9 at the output

Doing the maths in my head, that exactly matches what I'd expect based on the resistor values we have populated. So, it looks like we messed up the new output filter :(

Will have to think about what the right fix for this is.

hartytp, 2019-12-11:
Original filter design is here https://github.com/sinara-hw/Fastino/issues/4#issuecomment-529139058

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

hartytp, 2019-12-11:
Here is what we have in Fastino:

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

So it appears to be a copy-paste error. The Vref resistor should be the low value one, not the resistor to ground.

hartytp, 2019-12-11:
Looking over the filter design issue, it seems we decided to change the resistor values to 10k for a good reason https://github.com/sinara-hw/Fastino/issues/4#issuecomment-529142111

i haven't double checked the compensation capacitor value yet. @gkasprow if you have time can you fix the resistive divider one one channel and take a step response? That will let us check if the compensation is about right.

hartytp, 2019-12-11:
Anyway...this looks like a simple uncaught copy-paste error in the schematic. What do we do? Is it feasible to get this patched on all channels that have been produced by TS?

gkasprow, 2019-12-11:
we need to swap 2 resistors in the SOIC package.
We have one free 5V resistor that helps a bit. With a piece of thin wire and a lot of manual work we can patch it.

gkasprow, 2019-12-17:
The easiest way to go is to use an unused resistor between pads 2 and 7.
The operations to perform:
1. lift leg 1 of RN5
2. cut or lift leg 6 of RN5
3. short leg 7 with leg 8 of RN5
4. short leg2(lad2) with pad1 (but not lifted leg2)
5. with short piece of wire short leg 1 with pad 6.
6. repeat steps 1-5 32 times

I modified two amps and they generate correct 0V at the output with 2.5V at the DAC input.+

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

dnadlinger, 2019-12-17:
Oh dear, that sounds like a lot of work for 4 * 32 (?) channels! (I did point this out here https://github.com/sinara-hw/Fastino/issues/4#issuecomment-529154162, but unfortunately didn't look over the final schematics… :/)

gkasprow, 2019-12-17:
Unmodified boards are still working, only output is shifted by 2.5V offset

hartytp, 2019-12-18:
Okay good! So that’s basic testing complete. Good work!

 Now the priority is to get @jordens a patched board ASAP so he can complete software development. I’ll coordinate getting our boards patched with ts.

gkasprow, 2019-12-22:
I think I forgot to publish the photo
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

Closed 2019-12-18.

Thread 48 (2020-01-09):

i2c broken with AFE_PWR disabled

jordens, 2020-01-09:
* if the FPGA is not configured it does not enable the AFE power
* if the AFE power is not enabled, something pulls down the I2C bus
* this makes configuration via I2C impossible

jordens, 2020-01-09:
this may also apply to other boards where I2C is hooked up via a target-controlled switch to a configurable target.

jordens, 2020-01-09:
In fact i don't know why the source side is pulled down. The FPGA pins should be high-z

pathfinder49, 2020-01-24:
@gkasprow As far as I can tell, P12V0A and N12V0A are off until the FPGA is configured. This disconnects the i2c, preventing configuration.

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

gkasprow, 2020-01-24:
True, the idea was to disconnect I2C from FPGA until it is configured properly to not block the bus.

pathfinder49, 2020-01-24:
To avoid bypassing the power sequencing, I tried de-soldering R48 and connecting to REF_SHDN instead. This allows the 12V supply to start. However, En_AFE_PWR appears to be pulled low during flashing. Consequently the I2C disconnects again when flashing. Have you got another suggestion?

jordens, 2020-01-24:
No no. That's not the problem. The FPGA is not involved with I2C during flashing. Having it disconnected is completely fine. It's in fact the intention.

jordens, 2020-01-24:
There is also a faint glow on the P12V0A LED (and I think even N12V0A) with EN_AFE_PWR low which should not be there AFAIR.

jordens, 2020-01-24:
Additionally something is weird (compared to e.g. Banker) with the FPGA not loading its configuration (no CDONE) when reset (CRESET) via the I2C-SPI/GPIO extender. May be the same, may be something different.

pathfinder49, 2020-01-24:
> There is also a faint glow on the P12V0A LED (and I think even N12V0A) with EN_AFE_PWR low which should not be there AFAIR.

When EN_AFE_PWR is pulled to 0 V I measure no voltage on either P12V0A or N12V0A.
However, when unmodified EN_AFE_PWR is at 0.56 V. I then measure +2 V on the P12V0A and +0.6 V on N12V0A whith the P12V0A LED glowing slightly.

gkasprow, 2020-01-24:
I don't have any PCB to look at this.
Remove R42 and FPGA loading will work. At the moment the FPGA is loaded by PG signal

gkasprow, 2020-01-24:
the EN_AFE_PWR has 10k pulldown. Don't you have some FPGA pullup? It looks like we have to decrease the R48 to let's say 2k2

pathfinder49, 2020-01-24:
> No no. That's not the problem. The FPGA is not involved with I2C during flashing. Having it disconnected is completely fine. It's in fact the intention.

Excuse my ignorance, I thought the FPGA was flashed via I2C here. Am I missing something?
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

jordens, 2020-01-24:
The fpga has weak pullups when unconfigured. May need lower pulldown.
Still doesn't explain the failure to configure by creset though.

jordens, 2020-01-24:
The flash is flashed by i2c. The fpga is held in reset and is out of the loop.

pathfinder49, 2020-01-24:
The EEM0_I2C signal is switched off before this point as far as I can tell.

gkasprow, 2020-01-24:
The EEM I2C is routed to EEPROMs only. After FPGA wakes up, it enables P12V0A and enables access to the rest of the I2C tree.
This also means that the I2C extender is not connected to the EEM I2C until FPGA gets configured. THis needs to be fixed, the I2C extender should always be connected to the EEM I2C

gkasprow, 2020-01-24:
This also means that the I2C extender must be suplied from P3V3MP to not block the bus.

gkasprow, 2020-01-24:
as a temporary fix, short T6 and T9 (drain with source, pin 2 with pin 3)

jordens, 2020-01-24:
No. That's also irrelevant.

gkasprow, 2020-01-24:
@jordens do you mean that with unconfigured FPGA you can't access EEPROM?
With P12V0A high enough to make the LEDs glowing, it is enough to enable the MOSFET I2C switches which connect the bus to the FPGA. If the FPGA helds the IO pins low for some reason, the bus will be blocked.

jordens, 2020-01-24:
Yes. As the top post describes.

The fpga is not needed for programming. And the fpga does not drive the i2c bus. Not when configured and not when reset. Still the i2c bus is broken. And it's broken when afe pwr is **disabled**

jordens, 2020-01-24:
For me this also affected the lm75, not only the spi converter.

gkasprow, 2020-01-24:
LM75 is connected directly to the EEM connector. I'd removeT6, T9 and check if that helps.

pathfinder49, 2020-03-17:
@hartytp @gkasprow I'm just finishing the PR for the new Fastino revision. I've addressed most known issues. However I'm not sure what the way forward is here.

It would be good to arrive at a conclusion such that this can be fixed.

hartytp, 2020-03-17:
@pathfinder49 I don't feel qualified to make this call. The decision should come from @gkasprow or @jordens

pathfinder49, 2020-03-19:
@gkasprow @jordens It would be good to conclude this soon. I'd like to move on from the Fastino revison.

gkasprow, 2020-03-20:
@pathfinder49
- [ ] lower the R48 to let's say 2k2
- [ ] connect the I2C extender directly to the EEM0_I2C (before the T6,T9)
- [ ] connect IC10 supply and all config pins to P3V3_MP
this should solve all the issues.

gkasprow, 2020-05-20:
closing, in case the issue is not fixed we will reopen it.

Closed 2020-05-20.

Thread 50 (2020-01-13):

Channel SMPS/switching/SPI/update spur differences

jordens, 2020-01-13:
* Kasli, EEM0 -> Fastino channels 24-31 -> IDC-BNC
* battery powered
* modules close together (that does not make any difference)
* in a shielded crate (admittedly not fully RF-tight but that doesn't make a difference)
* voltages in the 6-9 V range (channel << 11 loaded into the DACs)
* all DACs continuously updating at 2.55 MS/s with 21 ns SPI period
* 6.9 kHz bandwidth, 1 M impedance, look at the green trace

The DAC channels are pretty different in terms of their spur performance. 27 is really nice and clean, 31/26/24 are pretty dirty. They have spurs at 450-600 kHz and in the MHz range.

Probably layout tightness, layer crossings, and general routing.

## channel 27:

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

## channel 24:

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

## channel 26:

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

## channel 31:

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

hartytp, 2020-01-13:
Many thanks for posting that data @jordens

To check I understand the units, is the worst-case spur you've observed something like `-85dBVrms=56uVrms`.

For a first hw revision, I find that pretty encouraging. The worst-case in-band voltage spurs are only something like 1 OOM above the noise floor and the high-frequency stuff should be okay to remove with a trap filter. Out of curiosity, what's the noise BW from these measurements/what in-band noise floor do you measure?

Still, worth looking again at the layout with this data and seeing what we can do to improve for the next revision...

hartytp, 2020-01-13:
Crudely, by eye, the filter response looks about right, which is good!

jordens, 2020-01-13:
See #51 for that.

dnadlinger, 2020-01-13:
Is this with the swapped output filter resistors manually reworked, or with an unmodified board (i.e. with the extra output offset)?

gkasprow, 2020-01-13:
@jordens did you try that on another Fastino board?

gkasprow, 2020-01-13:
Output traces of affected channels
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

gkasprow, 2020-01-13:
I don't see why these channels are noisy. Did you generate 3.125 sinewave on all outputs?
Can you measure the noise without updating the channels?

hartytp, 2020-01-13:
@gkasprow can you remind me which channel is which on that diagram? Also, can you remind me where the refs for each channel are routed?

hartytp, 2020-01-13:
> 27 is really nice and clean, 31/26/24

27 is right by the connect edge of the board, while 31/26 are close to the SMPS/FPGA so it somewhat makes sense they would be nosier.

24 is right next to 27 and derive from the same ref buffer so that difference isn't obvious.

gkasprow, 2020-01-13:
other channels like 23, 29 is as close as 31 and 26 to the SMPS. Channel 8 is the closes to the FPGA
Channels 29, 23, 26 are the closest to the SMPS.
SMPS is sitting on the copper island to avoid current loop below.

gkasprow, 2020-01-13:
It needs careful investigation. I'd disable the SMPS first or at least correlate its frequency with the spur.

hartytp, 2020-01-13:
Easier said than done. In most of our lab space I’d struggle to reproduce @jordens data since the ambient emi is a nightmare.

gkasprow, 2020-01-13:
The same in my lab. I have a few FM and DVBT transmitters nearby. It's impossible to measure 100mV 100MHz signal with a scope...

hartytp, 2020-01-13:
Supposedly our shiny new building will have low EMI. I've budgeted some time to test Fastino once the software is ready. If I can reproduce this then I'll have a look at it (I suspect the easiest thing is to measure the frequencies of the various noise sources and see how they compare to the measured spur frequencies).

gkasprow, 2020-01-13:
This is exactly what I do. Make a small air coil and sniff with scope in search of EMI sources.

jordens, 2020-01-14:
This is the only v1.0 I have with all output networks patched. The patch works. Voltages are ok.

I didn't generate a 3.125 sine wave (MHz? V?).

This is a 25 year old office building, with a massive mains/network/phone cable duct running 2 m away from the setup, a bunch of office and lab/RF equipment in the same room, a tram line outside in 50 m distance, the corresponding tram substation in 20 m distance, kitchen with microwave at 20 m, a forest of cell towers at 100 m (20m up), and other labs and companies doing high power audio and wireless development in the adjacent floors and buildings. Certainly not clean. It's a really nice exercise to figure out what matters and what doesn't matter.

The really weird difference is between 24 and 27.

hartytp, 2020-01-14:
> The really weird difference is between 24 and 27.

Indeed.

From a quick skim over the schematic, the most likely offender for the 450kHz stuff looks to be the 3V3 SMPS. It's also not filtered (beyond the main switching LC) and goes all over the board due to e.g. LEDS, signals like REF shutdown, etc. I haven't looked at the layout in enough detail to offer an explanation for the difference in noise between ch 24/27 though.

@jordens if you have time at some point, it would be really interesting to grab a trace of the P3V3 rail and compare the spectral content on that to the noisy DAC outputs.

jordens, 2020-01-14:
@gkasprow ah you mean the lowest FFT bin at 3.125 kHz? That's just window leakage from the DC 0 Hz bin.

pathfinder49, 2020-01-27:
I've just attempted to replicate this measurement on a 4GHz scope using a 500 MHz probe. I believe the noise peaks above are aliased.

Sampling at 20 MS/s (I believe this is how the above data was taken) I get this spectrum:
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

Sampling at 2 GS/s the 500 kHz features disappear and significant 100 MHz noise becomes apparent:
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

Sidenote: all channels I've looked at show a ~1 us beat between 100 MHz signals. The time basis trace looks like this:
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
Focusing on a noise spike we see this:
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

hartytp, 2020-01-27:
Glad you got that up and running. Let's have a look tomorrow, but I suspect that with a scope probe that's largely pickup from the lab.

gkasprow, 2020-01-27:
How did you connect the GND clip?
Please repeat the same measurement, with the same GND connection. Just touch the GND connection with the probe tip and post the results. In this way, you will measure what induces on the probe cable shield.

pathfinder49, 2020-01-28:
The GND clip is connected via a 20 cm ribbon cable. connecting to a header with soldered wires.

Here are 2 (savgol-filtered) measurements I made today. The y axis should be comparable.
| clipped on DAC P | Touching GND clip (not moved) |
|-----|-----|
| 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 |  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 |

gkasprow, 2020-01-28:
SO, you are essentially measuring the ground loop noise. Try to substract the two :)

pathfinder49, 2020-02-11:
> * all DACs continuously updating at 2.55 MS/s with 21 ns SPI period

@jordens How did you configure the DACs to continuously update? From our discussion on Mattermost it sounded like you didn't use DMA. However, I only see the SCLK toggling when
 my experiment continuously writes values to the DAC.

jordens, 2020-02-11:
You need to change the gateware to make it update all the time.

jordens, 2020-02-16:
> For a first hw revision, I find that pretty encouraging.

What's "good" level of spurs?
"One LSB" doesn't make much sense and figuring out a generic and practically meaningful bandwidth to integrate the wideband noise over is pretty much impossible.
But there is one value to compare the -87 dBV to: This is only 13 dB better than what would be allowed on conducted emissions on the power line coming from domestic device (CISPR 22 class B requires less than 46 dBµV).
Maybe something like -120 dBV (46 dB better than CISPR 22 class B and about 70 dB better than a 10 mV ripple on a SMPS power supply rail, depending on harmonic content) would be a worthy goal for a low-noise/low-spur DAC output.

hartytp, 2020-08-31:
@jordens any objections to closing this? This is quite different on the new layout and AFAICT most of the spurs you pointed to are gone.

jordens, 2020-08-31:
As long as you keep track of the underlying issue, sure.

hartytp, 2020-09-02:
> As long as you keep track of the underlying issue, sure.

For the avoidance of confusion, which issue exactly do you mean?

jordens, 2020-09-02:
Given that there are several issues potentially playing into this, we should document a specification for the spurs and ensure that we track and look at several/all channels and all spurs, each time there is an attempt to fix class of spurs. I don't have the overview of assigning the spurs displayed here to the different underlying issues (SMPS on 12V from Kasli, cross-talk from CS/CLK/MOSI through the chip, cross-talk from the terminations through vias or cuts or radiatively, cross-talk from the SMPS on Fastino, through the references or onto the analog path). But I'm happy if someone says that those issues are being addressed and are reasonably likely to have caused the spurs in v1.0.

hartytp, 2020-09-02:
ACK. I think all that information does exist in the issues, but not in a form that's easy to follow.

I believe that we understand the vast majority of the spurs now and v1.2 should be very clean (v1.1 already looks good on all but a few channels). It will be interesting to see the data though...

Closed 2020-08-31.

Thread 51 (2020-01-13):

Output noise

jordens, 2020-01-13:
# Conditions

* Kasli, EEM0 -> Fastino channels 24-31 -> IDC-BNC
* battery powered
* modules close together (that does not make any difference)
* in a shielded crate (admittedly not fully RF-tight but that doesn't make a difference)
* all DACs continuously updating (loading `channel_index << 11`) at 2.55 MS/s with 21 ns SPI period
* 1 M impedance, look at the green trace (A)
* using channel 27 which is a pretty clean one (#50) at 6.875 V output

# tl;dr:

* less than 80 nVrms/rtHz to 500 kHz
* less than 12 nVrms/rtHz above 2 MHz
* about 4 nVrms/rtHz at 10 MHz
* nice, stable, and low noise as by design, no surprises
* the 150 Hz stuff might be something with the reference or acoustics, and might be worth investigating

## 6.9 kHz bandwidth, to 10 MHz

-106 dBV are 60 nVrms/rtHz

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

## 6.9 Hz bandwidth, to 10 kHz

-137 dBVrms are 54 nVrms/rtHz

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

## 6.9 mHz bandwidth, to 10 Hz

-140 dBVrms are 1.2 uVrms/rtHz

(coming up in a couple hours)

## model from schematics

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

hartytp, 2020-01-13:
Nince! Thanks for the lovely data.

hartytp, 2020-01-13:
That looks like a pleasantly good fit to the model then.

jordens, 2020-01-13:
If somebody wants to investigate the 150 Hz bump feel free. Otherwise closing.

dnadlinger, 2020-01-13:
Not super important, but do you have a capture with the DACs in quiescent state as well? (I.e. does anything change apart from the clock feedthrough peak disappearing?)

dtcallcock, 2020-01-13:
I would be interesting to check the noise on the reference, both before and after the buffers (though it looks like there are only test points post buffers).

What is the P/N of C167 @gkasprow ?  Could that be the source of microphonics?

hartytp, 2020-01-13:
> If somebody wants to investigate the 150 Hz bump feel free. Otherwise closing.

Are you confident it's not 3*50Hz line noise?

gkasprow, 2020-01-13:
C167 is generic CC0603_10UF_10V_10%_X5R
True, it could be an ultrasound from SMPS. It would affect the reference.
I would focus on C6 and C9. They are used to generate references for channels 21,22,24,25,27,28,30,31.
In Altium indexes start from 1, not zero.

jordens, 2020-01-14:
On these quiescence only removes the update feedthrough at 2.55 MHz and multiples.
The 150 Hz bump is certainly not line noise. 150 Hz line noise is very narrow in Europe and less than 10 Hz even if running on a generator.

hartytp, 2020-02-07:
I wonder if the 150Hz noise is the related to the offset trim circuitry. It's maybe a little low frequency though?

gkasprow, 2020-02-12:
This can be easily verified by removing either IC27 / IC2 or R158, R127, R140, and R220. The reference will drop to 3.9V.

Closed 2020-01-13.

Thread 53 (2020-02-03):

IC3 (CC10-1212DF-E) housing not grounded

pathfinder49, 2020-02-03:
The IC3 housing is not grounded. Is this intentional?
I'm observing a 0.6 Vp-p, ~500 kHz oscillation relative to the board ground in the IC3 housing. I found this when investigating #50.
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

gkasprow, 2020-02-03:
Try grounding and see how it influences the noise.

hartytp, 2020-02-03:
Indeed, there are an extra 4 pins missing from that pin-out.

@gkasprow was there a deliberate reason for not grounding it, or was this an oversight?

@pathfinder49 as Greg says, try to solder those pins to the ground plane and see if that changes the noise. If it makes things better we should look again at the other designs using this part.

jordens, 2020-02-03:
* Datsheet says grounding is optional (n.b. SMD version can't be grounded) and that it may improve coupled noise
* The case is isolated
* Therefore, depending on how you ground it and what's coupling to the case and how, doing so may also make the coupled noise worse

jordens, 2020-02-03:
It's also only two pins, not four.

gkasprow, 2020-02-03:
In isolated designs, the EMI level depends where you connect the shield. In our case we do not use isolation, so connect it to the input ground. The metal case may be capacitively coupled with transformer and grounding may help or make it worse.

pathfinder49, 2020-02-03:
Here Are some spectra for Ch31 with the IC3 housing grounded and floated. Overall it seems like grounding shifts spurs to higher frequencies.

The casing was grounded with a wire from TP17 to one of the case pins.

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

hartytp, 2020-02-03:
> Overall it seems like grounding shifts spurs to higher frequencies. Overall spur power decreases.

Does it? From the data you posted it looks like not much has really changed there...

> The casing was grounded with a wire from TP17 to one of the case pins.

TP17 is really not the best place for this. Look at the layout...Greg has taken pains to create an "island" where as much of the SMPS current as possible flows to avoid common-impedance couplings (ground voltage changes due to the SMPS current). You're creating a pretty big antenna there.

As Greg suggested a few posts above, you really want to tie the shield to the SMPS input pin (look at the Henry Ott bible I gave you and he has a really nice section on why you always tie shields to the source ground for this kind of thing). In this case, that means connecting the screeing can to pin 3 of the SMPS.

pathfinder49, 2020-02-04:
I've measured the noise again with grounding to IC3 pin 3. I've also investigated the spur amplitude variability. There is no significant effect from the shielding.

pathfinder49, 2020-02-04:
I will investigate the if there is an effect when combined with the external power for #55.

pathfinder49, 2020-02-04:
Grounding the shield makes a large difference when eliminating 3V3MP noise. Unsurprisingly, the coupling to the output channels is channel dependent.

With the shield floated and external power applied I get these spectra.
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

Grounding the shield, the remaining spurs in ch31 dissapear. A new ~1MHz spur appears. This coincides with the N12V0A rail starting to oscillate (fix for #54 not applied)
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

Applying the #54 fix The ch31 spectrum becomes
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

hartytp, 2020-02-04:
Interesting...what's the physics here? Why is the PSU housing related to the 3V3MP?

hartytp, 2020-02-04:
And, can you confirm how you grounded that?

hartytp, 2020-02-04:
Can I double check your y-axis scale. Is it really dBmV? (not dBm etc). If it's really dBmV then that spur is 20nV RMS. Is that correct?

Also, what's the worst-case output for a channel now? Is it much worse that this one? If so, this is starting to look excellent! Do you see any digital update noise, or is that all higher frequency?

pathfinder49, 2020-02-04:
>
>
> And, can you confirm how you grounded that?

The IC3 case was grounded from pin 3 of IC3

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

The y axis is dBmV (over 1 Hz). The spectrum analyser is configured to give average (as oposed to peak) bin power. Therefore I expect the spur peaks to be underestimated.

hartytp, 2020-02-04:
aah, ok. Nit pick: I would label that `dBmV/Hz` which is dimensionally correct, rather than `dBmV (Hz)` which, to me, indicates that the units for `dBmV` are Hz. For spur hunting, peak power is a better unit, although, hopefully we can kill that last spur and only have noise left!

Any idea where that last one is from?

> The IC3 case was grounded from pin 3 of IC3

Well, that makes zero sense to me.

pathfinder49, 2020-02-04:
>
>
> Interesting...what's the physics here? Why is the PSU housing related to the 3V3MP?

Apologies, fixed.

hartytp, 2020-02-04:
AAh, you mean that this isn't 3V3MP noise, but rather than grounding the SMPS case this way significantly improves the noise. I assume your previous measurement didn't help because the case was grounded to a TP miles away.

So, we should make sure to have an issue about grounding the case that references this data. We should keep this in mind for other designs as well

hartytp, 2020-02-04:
Where is the 3V3MP noise? Or, are you running that off a separate (clean) PSU for now?

pathfinder49, 2020-02-04:
>
>
> Also, what's the worst-case output for a channel now? Is it much worse that this one? If so, this is starting to look excellent! Do you see any digital update noise, or is that all higher frequency?

I've checked channels 24-31 and they are all spur free aside from the single 1.2 MHz peak. I will investigate all channels once I've finished addressing #55.

pathfinder49, 2020-02-04:
> So, we should make sure to have an issue about grounding the case that references this data. We should keep this in mind for other designs as well

See title of this issue

hartytp, 2020-02-04:
I see, so this is using a separate PSU to remove the 3V3 noise.

So, just that and the final spur to find. Good work!

hartytp, 2020-02-05:
@gkasprow based on those results, I think we should consider grounding the PSU chassis to the input ground on all designs that use this part.

At the very least, let's do this via DNPd 0R resistors to make grounding later easy. But, based on this data I'd suggest we should populate those grounding resistors by default.

jordens, 2020-02-05:
Are you certain this is the correct conclusion?
Let's disentangle the observations: I see a clean spectrum above, ok. But where is the spectrum that shows that the floating shield is still a problem with the two issues you had (at least N12V0A oscillation, P3V3MP/P12V ground bounce, and measurement issues) eliminated?
I'm certainly fine with a DNP jumper, as long as it's DNP for now.

hartytp, 2020-02-05:
> Are you certain this is the correct conclusion?

Yes, but it's not clear from the above data (particularly given that some of the descriptions were incorrect).

There are three independent observations:
- N12V0A is slightly unstable, fixed by adding a capacitor. That's one spike
- Several spurs related to grounding when Fastino is connected to Kasli (more on that later). At least one fix for this is taking Kasli from the equation and powering Fastino from floating 3V3 and 12V0 lab supplies.
- Different spurs related to the PSU chassis grounding. These can be removed by grounding the SMPS shield to its input ground pin (the previous observation that the shield grounding did not help should be ignored, since the chassis was grounded to a test point on a different part of the board)

The spurs from these sources all occur at different frequencies. We've tried several different combinations of the fixes and reproducibly are able to isolate the causes/make the spurs come and go.

Based on that, I feel pretty confident that we understand this. If you (or anyone else) have time to apply the patch and check independently that's of course always appreciated.

hartytp, 2020-02-05:
Anyway, I do agree we need a summary of this with a clear description of what setups were used and what was measured. @pathfinder49 is planning to post that later on.

jordens, 2020-02-05:
Yes. Would be great to see that description and the measurement that shows the isolated difference.
I'd be happy to reproduce it.

hartytp, 2020-02-05:
Indeed. @pathfinder49 is doing a meticulous job of this, so I'll stop getting over-excited and wait for him to post results before commenting further :)

> I'd be happy to reproduce it.

Cool! Once the write-up is done, that would be useful confirmation.

pathfinder49, 2020-02-10:
[This comment](https://github.com/sinara-hw/Fastino/issues/55#issuecomment-584073610) should really have been in this issue.

The effect of grounding the sield is summarised by this plot *(explained in the linked comment).
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

Closed 2020-05-20.

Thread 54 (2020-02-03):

N12V0A oscillating on some boards

pathfinder49, 2020-02-03:
I have 2 Fastino boards for testing. One of these has a 20 mVp-p, ~1MHz oscillation in the N12V0A supply. The frequency of this oscillation does not appear to coincide with other frequencies observed on the board. This noise propagates couples with different amplitudes into various output channels.

Here are some supply noise spectra for comparison.
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

pathfinder49, 2020-02-03:
I believe I also saw the N12V0A supply oscillating on the other board in some configurations, but have been unable to replicate this.

hartytp, 2020-02-03:
Could be the load capacitance for the LDO (see the part data sheet section on stability/capacitance). Try adding an extra 10uF ceramic right by the LDO and see if that stabilizes it.

hartytp, 2020-02-03:
How do these spurs compare with the noise on the dac  outputs?

pathfinder49, 2020-02-03:
> How do these spurs compare with the noise on the dac outputs?

Dac outputs are the bottom grouping. Lowest trace is the noise floor.
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

hartytp, 2020-02-03:
Ok so the worst spurs are due to the 3V3MP and the N12VOA. Interesting.

pathfinder49, 2020-02-03:
> Ok so the worst spurs are due to the 3V3MP and the N12VOA. Interesting.

I'm currently investigating one other significant spur that seems to behave differently.

hartytp, 2020-02-03:
Will be interesting to see if a larger output capacitor fixes this. C30 is a 16V X50 22uF, minimum output capacitor is 10uF so I would have expected that to be stable. It's also possible that something else funny is going on with that rail...

pathfinder49, 2020-02-03:
Adding 10uF (x5R) in parallel to C30 resolves the oscillation.

hartytp, 2020-02-03:
Sounds like a marginal capacitance then.

@gkasprow can you check for other places in Sinara we're using this LDO please?

gkasprow, 2020-02-03:
16V 22uF X5R caapcitor has much less than 10uF. X7R would be better here
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

dnadlinger, 2020-02-03:
@hartytp: Seems like we have been shouting helpful suggestions at @pathfinder49 in parallel (and were both right!). Do you/do we have a Sinara review checklist template somewhere we could add this to?

hartytp, 2020-02-03:
> Do you/do we have a Sinara review checklist template somewhere we could add an item for this to? (It's a common, well-known trap, but still has bitten us more than once already.)

Nope, but we should. The main wiki would probably be the best place. IIRC someone uploaded a CERN hw review checklist there. But, a shorter debugging list with the things we always tend to get wrong would be helpful as well...

gkasprow, 2020-02-03:
It's well hidden here
https://github.com/sinara-hw/sinara/wiki/SchematicsReviewChecklist

Closed 2020-05-20.

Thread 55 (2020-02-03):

Kasli noise (3V3MP, P12V0 & Ground)

pathfinder49, 2020-02-03:
There is a 35 mVp-p, ~200 kHz oscillation in the 3V3MP supply. I suspect this noise to originate from Kasli.

This noise appears to couple into a lot of other supply voltages and causes several spurs in the output channels.

The coupling to the output channels appears to be dependent on grounding.

Here are some spur measurements for a variety of power supplies and output channels 24-31. The power supplies are labeled in the legend. The DAC outputs are the bottom grouping of traces with  the lowest (spur free) measurement representing the noise floor.
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

hartytp, 2020-02-03:
Interesting. The best test for that might be to try removing 3V3_MP from the ribbon cable and injecting an external 3V3MP from a bench PSU. If that removes the output spurs then we should look into filtering that on Fastino.

pathfinder49, 2020-02-03:
The previous plot was measured with no additional grounding attached to the board.

Attaching an additional ground to TP17, reduces the amplitude of the 3V3MP spurs.

The plot below shows the channel noise with this additional GND attached. The new traces around zero are the is the log ratio of the noise before and after. Peaks reducing in amplitude are indicated by a negative spike here.
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

hartytp, 2020-02-03:
> Attaching an additional ground to TP17, reduces the amplitude of the output spurs from the 3V3MP supply.

I don't understand what you did here...

pathfinder49, 2020-02-03:
I measured the channel outputs as before. The only difference is that a connection to (building) ground was clipped onto TP17. TP17 connects to the board ground.

pathfinder49, 2020-02-03:
The trace at the top indicates the spur difference due to this GND connection.

hartytp, 2020-02-03:
Sounds like common-mode noise coming from Kasli. Can you try powering Fastino from an external 12V and 3V3MP supply?

pathfinder49, 2020-02-03:
I've powered Fastino from an external supply and disconnected it from other devices.

Here a resulting noise spectrum. (Not entirely comparable as measured in a different location)

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

pathfinder49, 2020-02-03:
Looking at the external 3v3 supply there is 500 kHz saw-tooth like noise. This would explain the most significant spurs.

hartytp, 2020-02-03:
> Here a resulting noise spectrum. (Not entirely comparable as measured in a different location)

Cool! That's starting to look quite clean. Nice detective work!

So...to recap:
- you've removed some large spurs by stabilizing the N12V0 LDO
- you've removed more spurs by powering from an external LDO
- the remaining spurs at ~450kHz and harmonics are from a TBD source, quite possibly the +-13V SMPS
- the noise floor of that measurement (measurement BW) is comparable to the measurements that @jordens posted previously
- you don't see any channels being significantly worse than that?

If so, great!

I suppose the next thing is to do something like:
- use a scalpel to remove the P3V3MP wire from the ribbon cable
- use super glue / epoxy (hot glue isn't mechanically that great IME) to add some kind of connector to the board (e.g. one of those Molex KK series 2-pins, as the back side is fairly well-suited to glueing IME)
- crimp the 3V3MP wire onto a connector
- dead bug an RC/LC filter onto the connector and then wire the filter output to the ribbon cable connector
- add a wire to connect the filter output to the back of the header/ a 3V3 TP or any other suitable location
- verify the spurs are still gone

If so, we can easily fix this in the next revision by adding a filter.

hartytp, 2020-02-03:
AFAICT the 3V3MP current draw is low (a few mA?) so a 100R || 1uF filter should do a good job here.

dtcallcock, 2020-02-03:
>There is a 35 mVp-p, ~200 kHz oscillation in the 3V3MP supply. I suspect this noise to originate from Kasli.

Worth adding additional decoupling caps (between the fuse and the EEM connector) on Kasli v2 and Kasli-SOC whilst we still have the chance?

gkasprow, 2020-02-03:
P3V3MP is used only to supply I2C memory, thermostat, and some logics. It's better to add a blocking cap at the EEM boards. There can also be ripples coming from ground bouncing or 12V return current.

gkasprow, 2020-02-03:
Before you claim any oscillations/ripples, first short probe tip to the place you connected the crocodile :)

pathfinder49, 2020-02-04:
I do not observe the oscillation when grounding the shield from IC3 pin 3, so shouldn't be relevant.

pathfinder49, 2020-02-04:
I had missed the P12V0 rail in my earlier measurments. The noise here is similar to the 3V3MP noise. I will investigate the effect of filtering either/both of these.

pathfinder49, 2020-02-04:
I've added a 16.2 kHz LC and 1.6 kHz RC filters onto P12V0 and P3V3MP respectively. This cleans up the respective board voltages nicely. However, this filtering does not replicate the behavior when disconnected from Kasli and powered from an external supply (see below).

Specra measured on ch31
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

For comparison powering Fastino simply from an external supply (also ch31).
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

pathfinder49, 2020-02-04:
A preliminary look on a scope suggests the I2C lanes may be coupling to the outputs. (The only EEM lanes with ~250 kHz features). I'll Investigate more properly tomorrow.

hartytp, 2020-02-05:
@gkasprow as @pathfinder49 will write up shortly, the remaining spurs are a ground-loop involving Kasli and our spectrum analyser.

There are a few ways this can be resolved, but it got me thinking more generally about EEM grounding. Specifically: is it necessary/correct to tie all the ground pins from the EEM cable to the EEM circuit ground? Are the grounds separating the LVDS lines really grounds, or more like screening? If the latter, shouldn't they be only connected at the source end? Maybe ground these via DNPd 0R resistors so we can change later?

gkasprow, 2020-02-05:
These EEM GNDs serve two purposes: they define differential impedance and provide lane screening; they are also 12V return path.
The DC/DC converter is quite well decoupled from EEM connector, I added LC filter also at its input to make sure it won't propagate the current spikes to the inside of the chassis.
It's worth supplying Kasli from linear bench PSU to make sure the 12V SMPS is not an issue here.
Another way of killing the ground loops is using magnetics. You can easily buy[ IDC tape ferrites ](https://www.conrad.com/p/wurth-elektronik-we-flat-7427224-ferrite-rod-core-115-l-x-w-x-h-28-x-146-x-77-mm-1-pcs-1086920)that increase the ground loop impedance for higher frequencies.
I wouldn't touch individual EEM cable grounds.

Fastino has the output CMCs disabled by default, It would be worth adding them at least on some channels. Make sure that DC is not passing through the return current because just milliamps saturate the core. One can also add ferrite core at the coax cable output. Take into account that all these ferrites work only for AC and it is extremely easy to saturate them if the return DC current is not passing the same way back through the core. In such case, they don't work at all.

hartytp, 2020-02-05:
> It's worth supplying Kasli from linear bench PSU to make sure the 12V SMPS is not an issue here.

Yep, that's one of the things on our to do list (I'm getting ahead of myself here while @pathfinder49 does the real work). It's possible that some of the spurs we see here are EMI/grounding on the 12V PSU.
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
jordens, 2020-02-05:
Ah. There is another potential problem with the those chokes, right? The DC return current corresponding to a channel's forward current will generally be shared among many channels. I.e. there is a severe DC current mismatch in all the chokes and thus saturation is likely. Obviously only relevant for applications where the load is low-ish impedance (at DC).

hartytp, 2020-02-05:
Not relevant to this case, but yes, that does sound like a potential issue. NB we haven't taken any data without those chokes so can't confirm if removing them would make the spurs worse. @pathfinder49 could you try doing that (just desolder one and replace with a piece of wire). If the chokes don't actually help with this kind of issue we should strongly consider DNPing them by default.

jordens, 2020-02-05:
The other problem with the chokes that I see (but we discussed that before), is that they take all the ground loop currents (at their very low impedance) and imprint them onto the (very high impedance) signal. Or in different and probably more correct words, the massive mismatch between the 50 R source impedance on Fastino and the extremely high impedance at the load in combination with the usual ground loop bypass (by other means) does not look good for the choke behavior.

jordens, 2020-02-05:
> Replace the 12V SMPS we're currently using with a floating 12V bench supply

The class II supplies also do that nicely.

NB: I haven't seen any issues in #51 from Kasli that I can't explain and eliminate.

> All we can say right now is that it is possible to get spur-free performance in Fastino (at the level we can measure on our SA with 100Hz BW) with appropriate grounding...

Sure. See #51

Also for the spur measurements, I suspect you haven't looked at the SPI spurs and DAC update spurs yet, right? If you are using the standard gateware/phy you won't be doing much SPI traffic.

gkasprow, 2020-02-05:
One can also take longer IDC cable, fold it, take big ferrite core with high permeability and make a few turns. This will work for kHz range as well.

dtcallcock, 2020-02-06:
> The spurs here are pretty low frequency (hundreds of kHz) which is far too low for any ferrite I'm aware of to work.

They make special low frequency cores that can give you modest impedances down to 100kHz.

[Fair-rite](https://www.fair-rite.com/wpapers_anotes/ferrite-cores-for-low-frequency-emi-cable-suppression-2/)
[Wurth](https://www.we-online.com/catalog/en/WE-STAR-FIX/)
[Laird](https://www.laird.com/emc-components/ferrite-cable-cores/round-and-cylindrical-cores/low-frequency-ferrite-cores/lfb-low-frequency-ferrite-core)

Unfortunately nobody seems to make one of those nice flat rectangualar ones that clamp on to a ribbon cable in these materials.

pathfinder49, 2020-02-10:
As requested in #56, here is some more data on the effect of grounding the IC3 housing with the other fixes applied.

Configuration (more details in #56):
*  Kasli on isolated and filtered PSU.
*  Capacitors added to FL1 on Kasli.
*  Grounding strap from Fastino front-panel.
*  Additional N12V0A capacitor to fix #54.
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

Removing the ground strap gives similar results with additional spurs as per #56.
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

hartytp, 2020-02-10:
@pathfinder49 can you clarify something here please? The legend indicates that the ground strap was only used for the orange curves, not for the blue curves. I assume that's a typo and you used the same grounding strap for both measurements in each plot?

i.e. in each plot the only difference between the blue and orange curves is whether IC13's case is grounded? And, the observation is that grounding the chassis removes several spurs without adding any new ones?

pathfinder49, 2020-02-10:
That was indeed a typo. The legends should now be correct.

jordens, 2020-02-10:
Nice! Thanks. Very convincing.

In the second plot, are there spurs at 0.9, 1.2, and 1.33 MHz on the blue curve as well (can't tell from the plot)? Or is that an intermittent emission from the BEC guys?

hartytp, 2020-02-10:
> In the second plot, are there spurs at 0.9, 1.2, and 1.33 MHz on the blue curve as well (can't tell from the plot)? Or is that an intermittent emission from the BEC guys?

hartytp, 2020-02-10:
They're there on both curves with (to within the noise) the same magnitude and are unrelated to the SMPS shield grounding. They are due to other noise sources, such as pick up and grounding and are improved in this configuration by the addition of the grounding strap.

Closed 2020-02-19.

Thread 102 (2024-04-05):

Shorting reference supplies

marmeladapk, 2024-04-05:
It's possible to short reference voltages with SW2. Maybe use jumpers or spdt switches?

gkasprow, 2024-04-09:
I don't want to increase the BOM, nothing will break this way

Closed 2024-04-22.

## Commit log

2019-09-07 initial sch and PCB
    [Fastino.PrjPCB, Fastino.schdoc, Fastino_DAC_channel.SchDoc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]
2019-09-08 ICE40 version
    [Fastino.schdoc, Fastino_DAC_channel.SchDoc, Fastino_FPGA.SchDoc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]
2019-09-15 Add output stage LTspice files
2019-10-16 99% routing done
    [Fastino.PrjPCB, Fastino.schdoc, Fastino_DAC_channel.SchDoc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]
2019-10-27 v1.1rc3 fixed #39
    [Fastino.schdoc, Fastino_FPGA_Config.SchDoc, Fastino_Power_Budget.xlsx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]
2019-10-27 cosmetic update
    [Fastino.schdoc]
2020-04-22 v1.1 fixes by @pathfinder49
    [Fastino.PrjPCB, Fastino.schdoc, Fastino_DAC_Series_Termination.SchDoc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]
2020-09-02 v1.2rc1 fixed issues with via to CH8 coupling; 1V2, 3V3 FPGA power integrity, added copper guard
2020-09-29 Ensure GND between analogue out and Digital vias
2025-11-17 v1.31 rc1
    [Fastino-connectors.schdoc, Fastino_DAC_Series_Termination.SchDoc, Fastino_DAC_channel.SchDoc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]
